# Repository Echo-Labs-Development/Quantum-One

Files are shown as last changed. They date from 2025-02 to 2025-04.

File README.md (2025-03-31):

# Quantum-One
> [!CAUTION]
> Building this machine is a very large undertaking and might pose serious safety risk if done incorrectly. This machine if not respected can start on fire, burn you, electrocute you, and hurt you in many other ways. Please use common sense when build this machine and stay safe.

> [!WARNING]  
> This project is currently in a unfinished state. Curently the parts a documentation do not exisit to build a working machine. This mesage will be updated when this stament has changed

Current State

## Journal
You can read the development log at:
https://github.com/Echo-Labs-Development/Quantum-One/blob/main/plan.md

## BOM (Bill of Meterials)
You can review the BOM at:
https://github.com/Echo-Labs-Development/Quantum-One/blob/main/BOM.md

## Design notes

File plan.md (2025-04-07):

Quantum One Logo

## Project Information

Made by: Henry([@HenryNerd](https://github.com/HenryNerd))

Repository Link: [https://github.com/Echo-Labs-Development/Quantum-One](https://github.com/Echo-Labs-Development/Quantum-One)

Total Hours: 75 Hours
## BOM
[BOM.md](https://github.com/Echo-Labs-Development/Quantum-One/blob/8280ed5a5fece50f8bd1d9ca4763da4ab5bdc901/BOM.md)

## Design Considerations

### Goals
- Quiet enough to be next to you on your desk
- Easliely Hackable
- Good Looking
- Buildable for anyone
- 220x220 minium build space
- Most Parts Printable
- Dosen't Start On Fire

### Specifications
- Core-XY
- Klipper Powered

## Time Log
| Date | Time |
| --- | --- |
| 2.1.25  | 2 Hours |
| 2.2.25  | 4 Hours |
| 2.3.25  | 5 Hours |
| 2.5.25  | 1 Hours |
| 2.8.25  | 6 Hours |
| 2.17.25 | 6 Hours |
| 2.18.25 | 4 Hours |
| 2.23.25 | 5 Hours |
| 2.24.25 | 2 Hours |
| 2.25.25 | 2 Hours |
| 2.26.25 | 2 Hours |
| 2.28.25 | 4 Hours |
| 3.3.25  | 2 Hours |
| 3.8.25  | 5 Hours |
| 3.18.25 | 6 Hours |
| 3.19.25 | 4 Hours |
| 3.28.25 | 4 Hours |
| 3.29.25 | 2 Hours |
| 3.30.25 | 6 Hours |
| 4.3.25  | 3 Hours |

## Design Milestones
### Skirt
2.1.25 - 2.8.25
- Made mounts for Pi 5 and BTT Octopus v1.1
- Added builtin mounting for frame
- Allowed screwing quarters together for smaller build volume
## Frame
2.17.25 - 2.18.25
- Attempted to add compatibility with enclosing in the future
- Made out of 2020 aluminum extrusion
- Made Sturdy and square

## Gantry
2.23.25 - 2.28.25
- Made Core-XY for faster print speeds
- Used MGN12H Rails for decent strength with small form factor
- Designed first revison of the toolhead

### Toolhead
3.3.25 - 3.19.25
- Designed toolhead revisions 2 - 4
- Repositioned hotend for more z hight

### Minor Fixes and Repositioning 
3.19.25 - 3.29.25
- Added Z Axis
- Design Bed Mount
- Moved Power Supply to Back

### Toolhead Redesign
3.29.25 - 4.3.25
- Fixed Cooling Ducts
- Repositioned Fans
- Made slimmer form factor
### Documentation
4.3.25 - Present
- Rewrote Journal
- Made Documentation more clear
- Wrote BOM

## Project Roadmap
- [x] Create CAD Model
- [ ] Obtain Funding
- [ ] Order Parts
- [ ] Assemble working machine
- [ ] Tune machine to create high quailty parts
- [ ] Persent Machine at Rocky Mountain Rep Rap Fest
- [ ] Create Build Documentation

## Project End Goal
- Good looking on your desk
- Creates high quailty parts
- Reliable operation
- Fully open source
- Documented for anyone to build

## Power Calculations
| Item | Power Draw |
| --- | --- |
| PCB Bed Heater | 200w |
| Hotend Ceramic Heater | 70w |
| | 270w |

## Meteorite Toolhead

## Design

### Parts
- LDO Orbiter v2.0
- Triangle Labs CHC V6
- 4010 Blower Fan
- 3010 Fan

### Design Considerations
- Heats up quickly
- Mounts directly onto rail
- Direct Drive
- Cheap
### Rev 01
M01

### Rev 02
M02

### Rev 03
M03

### Rev 04
M04

### Rev 05
M05

### Why These Parts
Orbitor 2 - From LDO comes with high quality steeper motor + all in one solution

Triangle Labs CHC V6 - Had really high power heater plus is souposed to have higger flow rate then regular V6

## Project Timeline

Mar 31st - Finish Design

Apr 10th - Start Build

Apr 15th - Finish Build

Apr 20rd - Finish Tuning

May 2nd - Ship to RMRRF

May 16th - Ship Myself to RMRRF

## Featured Parts
### XY Stepper Mount
XY Stepper Mount

Why Core-XY: I wanted to build a core xy because first of all they are really compact. Second I already own a bed slinger 3d printer. Also the belt routing really interested me.
### Power Supply Mount
Power Supply

Changes: Had to move power supply out of the skirt to make space for Z steppers

## Spark Console

### Why
I din't want to have a big touchscreen in the center of the machine. I wanted to go for something quince. I chose to have an OLED screen on it to have because it dose not steal the spotlight but can still display useful information. I also added neopixels so that it could have a progress bar that reacts to the current state. Finally I added 8 buttons for commonly used actions for anything more complex you probably want to use the web UI anyway.

### Parts
- XIAO rp2040
- Kailh Chocs
- Adafruit Neoxpixels
- 128x32 OLED

Schematic
Half Finished Skirt

PCB Render
Half Finished Skirt

PCB Layout
Half Finished Skirt

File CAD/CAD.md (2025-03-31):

# CAD Model
All models designed in Autodesk Fusiom 360

You can view the CAD Model at: https://autode.sk/4iUQ1s4

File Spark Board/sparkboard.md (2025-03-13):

# Spark Board
A Screen free controller for the Quantum One 3d printer

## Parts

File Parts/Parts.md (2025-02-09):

# Printed Parts

| Part # | Descrption |
| --- | --- |
| #001 | Skirt Pice |
| #002 | Skirt Pice |
| #003 | Skirt Pice |
| #004 | Skirt Pice |

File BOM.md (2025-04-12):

# Quantum One BOM

| Item Name | Link | Quantity | Price  |
| --- | --- | --- | --- |
| BIGTREETECH Octopus V1.1 | https://biqu.equipment/products/bigtreetech-octopus-v1-1?variant=39749193990242 | x1 | $59.65 |
| LDO Orbiter Extruder V2.5 | https://biqu.equipment/collections/ldo/products/biqu-orbiter-v1-5-extruder-dual-driver-gear-extrusion-3d-printer-parts-for-cr10-10s-ender3-3-pro-ender5 | x1 | $51.42 |
| 2020 Aluminum Extrusion 250mm | https://us.misumi-ec.com/vona2/detail/110302683830/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 | x4 | $18.16 |
| 2020 Aluminum Extrusion 290mm | https://us.misumi-ec.com/vona2/detail/110302683830/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 | x4 | $18.16 |
| 2020 Aluminum Extrusion 225mm | https://us.misumi-ec.com/vona2/detail/110302683830/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 | x1 | $4.54  |
| 2040 Aluminum Extrusion 270mm | https://us.misumi-ec.com/vona2/detail/110302684350/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 | x1 | $8.46  |
| Trianglelab CHC Pro Volcano | https://www.aliexpress.us/item/3256803662839179.html?gatewayAdapt=glo2usa4itemAdapt | x1 | $23.39 |
| C14 Plug | https://www.aliexpress.us/item/2251832612090578.html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 | x1 | $0.99  |
| RJ-45 Plug | https://www.adafruit.com/product/4130 | x1 | $5.95  |
| USB-C Plug | https://www.adafruit.com/product/4259 | x1 | $5.95  |
| Mean Well LRS-350-24 | https://www.aliexpress.us/item/2255800177960035.html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 | x1 | $33.82 |
| GT2 Pully | https://www.aliexpress.us/item/3256807346746485.html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 | x1 Pack of 10  | $0.99  |
| T8 Lead Screw | https://www.aliexpress.us/item/3256807640425926.html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 | x1 Pack of 3 | $3.64  |
| T8 Lead Screw Coupler | https://www.aliexpress.us/item/2255799990666860.html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 | x1 Pack of 5 | $0.99  |
| 250 MGN12H 250mm | https://www.aliexpress.us/item/3256803270722742.html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,scm-url:1007.40050.354490.0,pvid:600005ca-71c2-4983-86be-b219b2e41406,tpp_buckets:668%232846%238107%231934&pdp_ext_f=%7B%22order%22%3A%2256%22%2C%22eval%22%3A%221%22%2C%22sceneId%22%3A%2230050%22%7D&pdp_npi=4%40dis%21USD%214.86%213.69%21%21%214.86%213.69%21%402103277f17433710452667490e7706%2112000027738617458%21rec%21US%21%21ABXZ&utparam-url=scene%3ApcDetailTopMoreOtherSeller%7Cquery_from%3A | x2 Pack of 2 | $48.54 |
| Raspberry Pi 5 4 GB | https://www.adafruit.com/product/5812 | x1 | $60.00 |
| Raspberry Pi Active Cooler | https://www.adafruit.com/product/5815 | x1 | $6.58  |
| Raspberry Pi RTC | https://www.adafruit.com/product/5817 | x1 | $5.00  |
| Aluminum Heat Bed | https://www.aliexpress.us/item/3256807168211535.html | x1 | $13.93 |
| 3010 24v Fan | https://www.aliexpress.us/item/3256801117079696.html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 | x1 | $0.99  |
| 4010 24v Blower Fan | https://www.aliexpress.us/item/3256804907966353.html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 | x1 Pack of 2 | $0.99  |
| V6 Hotend Holder | https://www.aliexpress.us/item/3256803323301635.html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 | x1 | $1.97  |
| 16 AWG Black Silicone Wire | https://www.aliexpress.us/item/3256806379805687.html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 | x1 (20m Black) | $3.73  |
| 16 AWG Red Silicone Wire | https://www.aliexpress.us/item/3256806379805687.html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 | x1 (20m Red) | $3.73  |
| 5 Pack NEMA 17 | https://www.aliexpress.us/item/3256802068491329.html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 | x1 Pack of 5 | $26.49 |
| GT2 Timing Belt  | https://www.aliexpress.us/item/3256803076577178.html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 | x1 pack 20m black | $12.68 |

# Screws

| Screw | JLCMC Part # | # of Screws | Total Price |
| --- | --- | --- | --- |
| M3x10 | EDLA-S1-M3-L10 | 25 | $0.11 |
| M6x12 | EDLA-S1-M6-L12 | 15 | $0.26 |
| M4x16 | EDLA-S1-M4-L16 | 10 | $0.11 |
| M6x30 | EDLA-S1-M6-L30 | 7 | $0.21 |
| M6x70 | EDLA-S1-M6-L70 | 7 | $0.42 |
| M3x16 | EDLJ-S1-M3-L16 | 10 | $0.05 |
| M2.5x12 | EDLA-S1-M2.5-L12 | 10 | $0.07 |
| M3x16 | EDLA-S1-M3-L16 | 10 | $0.07 |
| M4x12 | EDLA-S1-M4-L12 | 50 | $0.44 |
| M4 Nut  | TPBB-N-10-M4 | 50 | $0.99 |

# Total Cost ~ $339.41

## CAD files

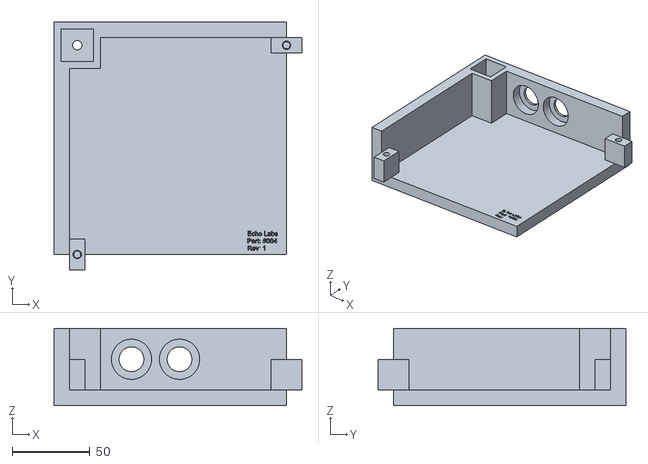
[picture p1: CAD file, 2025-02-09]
Parts/#003.stl
160.0 x 160.0 x 50.0

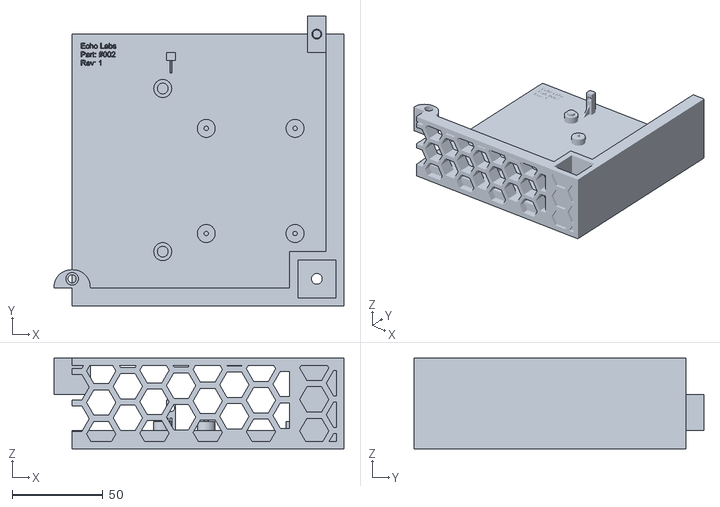
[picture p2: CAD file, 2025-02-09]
Parts/#002.stl
160.0 x 160.0 x 50.0

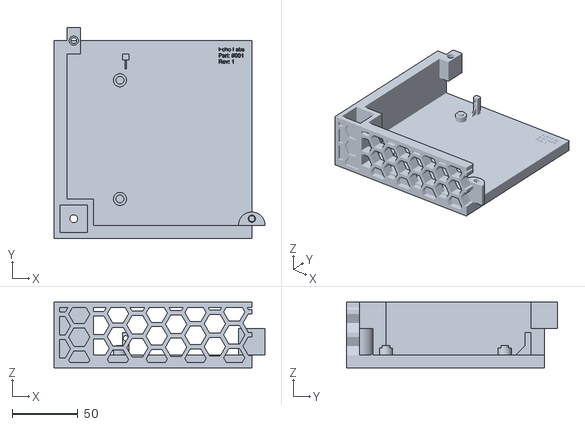
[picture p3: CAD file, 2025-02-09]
Parts/#001.stl
160.0 x 160.0 x 50.0

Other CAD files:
Parts/#004.stl
